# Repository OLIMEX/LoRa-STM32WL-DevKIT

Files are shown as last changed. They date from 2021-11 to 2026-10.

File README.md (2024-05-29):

# LoRa-STM32WL-DevKIT
STM32WL SOC LoRa / LoRaWAN development board with JTAG debugger and sensors for light (photoresistor), temperature and humidity (AHT20, BME280 in older revisions), and 3-axis digital magnetometer (IIS2MDCTR)

Product page: https://www.olimex.com/Products/IoT/LoRa/LoRa-STM32WL-DevKit/

## License
* Hardware design is released under CERN OHL v1.2 license
* Software is released under GPL3 License
* Documentation is released under CC BY-SA 3.0

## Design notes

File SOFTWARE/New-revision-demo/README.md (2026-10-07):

# LoRa-STM32WL-DevKIT LoRaWAN demos for BB-STM32WL revision D1

This folder contains two LoRaWAN end-device demo projects for the Olimex
**LoRa-STM32WL-DevKIT**. They are intended **only for boards fitted with a
BB-STM32WL module marked hardware revision D1**.

For BB-STM32WL revision C or older, use the legacy project and instructions in
[`../Old-revision-demo`](../Old-revision-demo/) instead.

> [!IMPORTANT]
> These projects contain the RF front-end control required by BB-STM32WL
> revision D1. Do not use the binaries on an older BB-STM32WL revision. Check
> the revision marking printed on the module before building or programming.

Always connect an antenna suitable for the selected frequency band before
powering the radio or running the demo.

## Included projects

| Project | LoRaWAN region | Intended use | Demo uplink |
| --- | --- | --- | --- |
| [`LoRaWAN/868/LoRaWAN-868MHz`](LoRaWAN/868/LoRaWAN-868MHz/) | EU868 | Europe and other locations where the EU868 regional parameters are permitted | Unconfirmed message on FPort 2 every 10 seconds; 3-byte temperature/battery test payload |
| [`LoRaWAN/915/LoRa-WAN-915MHz`](LoRaWAN/915/LoRa-WAN-915MHz/) | US915 | North America and other locations where the US915 regional parameters are permitted | Confirmed message on FPort 2 every 10 seconds; 3-byte temperature/battery test payload; configured for US915 sub-band 2 |

The demo payload in both projects is encoded as follows:

| Byte(s) | Value |
| --- | --- |
| 0-1 | Signed 16-bit temperature in degrees Celsius, most-significant byte first |
| 2 | Firmware battery scale: `0` is below the configured minimum, `1` is very low, and `254` is full |

Both applications use OTAA, LoRaWAN Class A, the STM32WLE5CCU6 internal
sub-GHz radio, and UART diagnostic output at 115200 baud. The D1 RF switch is
controlled through `FE_CTRL1` on PC13 and `FE_CTRL2` on PB8.

The selected radio band must be legal in the country of operation and must
match both the gateway and the device profile in the LoRaWAN network server.
The customer is responsible for observing local radio regulations, including
duty-cycle and transmit-power limits.

## Software to use

### Editing and building

Use the Eclipse-based [STM32CubeIDE](https://www.st.com/en/development-tools/stm32cubeide.html).
The repository already contains the STM32 HAL, CMSIS, LoRaWAN middleware, and
the Eclipse project metadata, so a separate middleware download is not needed
for a normal build.

The `.ioc` files were generated with:

- STM32CubeMX 6.17.0
- STM32CubeWL firmware package 1.5.0
- GCC / STM32CubeIDE project format

A newer STM32CubeIDE may offer to migrate the project. Back up local changes
before accepting migration. If pin or middleware code must be regenerated,
use STM32CubeMX 6.17.0 with STM32CubeWL 1.5.0 to minimize generated-code
differences.

### Programming the board

Use [OpenOCD](https://openocd.org/) with the board's built-in CMSIS-DAP probe.
The supplied `flash.sh` scripts use USB VID:PID `15ba:0044`, SWD at 1 MHz, and
the OpenOCD `stm32wlx` target.

STM32CubeIDE can build the firmware, but its normal ST-LINK programming flow is
not the programming method for the onboard CMSIS-DAP probe. STM32CubeProgrammer
is also not required for the supplied onboard-probe workflow.

On Linux, the helper script additionally uses `picocom` for the serial log.
On Windows, use OpenOCD to program the ELF file and any serial-terminal program
(for example PuTTY or Tera Term) to view the virtual COM port.

### LoRaWAN service

A compatible LoRaWAN gateway and network server are required. The Things Stack,
ChirpStack, or another standards-compatible LoRaWAN network server can be used.
Create the end device as an OTAA device and select the same regional frequency
plan as the firmware.

## Configure the OTAA credentials

Each physical device must have unique production credentials. Edit
`LoRaWAN/App/se-identity.h` in the selected project and set:

- `LORAWAN_DEVICE_EUI` (DevEUI). If it remains all zero, the firmware derives a
  value from the STM32 unique device information; register the resulting value
  shown in the serial log.
- `LORAWAN_JOIN_EUI` (called AppEUI by LoRaWAN 1.0.x network servers).
- `LORAWAN_GEN_APP_KEY` (AppKey for LoRaWAN 1.0.x).
- `LORAWAN_APP_KEY` (NwkKey for LoRaWAN 1.1.x).

The values included in the source are examples and must not be reused for a
deployed device. Keep production root keys private and do not commit them to a
public repository.

Credential files:

- EU868: `LoRaWAN/868/LoRaWAN-868MHz/LoRaWAN/App/se-identity.h`
- US915: `LoRaWAN/915/LoRa-WAN-915MHz/LoRaWAN/App/se-identity.h`

## Build

### EU868

1. In STM32CubeIDE, select **File > Import > General > Existing Projects into
   Workspace**.
2. Select `LoRaWAN/868/LoRaWAN-868MHz` as the project directory.
3. Select the **Release** configuration and build the `LoRaWAN-868MHz` project.
4. The expected image is
   `LoRaWAN/868/LoRaWAN-868MHz/Release/LoRaWAN-868MHz.elf`.

The outer `LoRaWAN/868` directory also contains an exported source/build copy
and Eclipse metadata. Use the self-contained project path above for a clean
import, and do not import both copies into the same STM32CubeIDE workspace
because they use the same Eclipse project name.

### US915

1. In STM32CubeIDE, select **File > Import > General > Existing Projects into
   Workspace**.
2. Select `LoRaWAN/915/LoRa-WAN-915MHz` as the project directory.
3. Select the **Release** configuration and build the `LoRa-WAN-915MHz` project.
4. The expected image is
   `LoRaWAN/915/LoRa-WAN-915MHz/Release/LoRa-WAN-915MHz.elf`.

## Program and monitor on Linux

Install OpenOCD and picocom, connect the DevKIT's USB port, and run the helper
from the selected project directory:

```sh
# EU868
cd LoRaWAN/868/LoRaWAN-868MHz
./flash.sh

# US915
cd LoRaWAN/915/LoRa-WAN-915MHz
./flash.sh
```

The script erases the target, programs and verifies the Release ELF, resets the
board, and opens `/dev/ttyACM0` at 115200 baud. If the serial port has a
different name, run OpenOCD manually and open the correct port in picocom.

For either project, pass `--erase-nvm` when changing credentials or when a
stored network session prevents a clean join:

```sh
./flash.sh --erase-nvm
```

## Program manually with OpenOCD

Run from the directory that contains the chosen `Release` folder:

```sh
openocd -f interface/cmsis-dap.cfg \
  -c "cmsis_dap_vid_pid 0x15ba 0x0044" \
  -c "transport select swd" \
  -c "adapter speed 1000" \
  -f target/stm32wlx.cfg \
  -c "program Release/PROJECT_NAME.elf verify reset exit"
```

Replace `PROJECT_NAME.elf` with `LoRaWAN-868MHz.elf` or
`LoRa-WAN-915MHz.elf`. The same command structure can be used from Windows
PowerShell or Command Prompt if `openocd` is on `PATH`; omit the Unix line
continuation characters as appropriate.

## Serial output and first join

Open the board's virtual COM port with these settings:

- 115200 baud
- 8 data bits
- no parity
- 1 stop bit
- no flow control

After reset, the firmware prints its LoRaWAN identity and join status. Confirm
that the DevEUI printed by the board is the DevEUI registered in the network
server. A successful OTAA exchange is followed by `JOINED`/`[DONE]` and then
periodic uplink messages.

If the device does not join:

1. Verify that the module is BB-STM32WL revision D1.
2. Verify the antenna and the selected EU868 or US915 project.
3. Check that DevEUI, JoinEUI/AppEUI, AppKey, and NwkKey match the network
   server exactly, including byte order.
4. For US915, configure the gateway/network frequency plan for sub-band 2.
5. Erase the saved LoRaWAN context after changing credentials, then reset and
   try again.
6. Check the 115200-baud serial log for `JOINFAIL`, radio, or programming
   errors.

## Main configuration files

| Setting | File in each project |
| --- | --- |
| OTAA identifiers and keys | `LoRaWAN/App/se-identity.h` |
| Active region, uplink interval, and FPort | `LoRaWAN/App/lora_app.h` |
| Join, transmit, receive, and demo-payload logic | `LoRaWAN/App/lora_app.c` |
| Compiled regional support | `LoRaWAN/Target/lorawan_conf.h` |
| D1 RF front-end switching | `LoRaWAN/Target/radio_board_if.c` and `.h` |
| Clock, GPIO, USART, and MCU configuration | project `.ioc` file |

## References

- [LoRa-STM32WL-DevKIT product page](https://www.olimex.com/Products/IoT/LoRa/LoRa-STM32WL-DevKit/open-source-hardware)
- [Olimex LoRa-STM32WL-DevKIT repository](https://github.com/OLIMEX/LoRa-STM32WL-DevKIT)
- [STM32CubeIDE](https://www.st.com/en/development-tools/stm32cubeide.html)
- [OpenOCD](https://openocd.org/)

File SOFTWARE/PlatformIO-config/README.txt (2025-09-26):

Board description for platformIO. 

It was tested only with the Arduino framework (not cmsis nor stm32cube).

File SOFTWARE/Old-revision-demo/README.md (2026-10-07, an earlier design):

# LoRa-STM32WL-DevKIT demo for BB-STM32WL revision C and older

This folder contains the legacy EU868 LoRaWAN sensor demo for the Olimex
**LoRa-STM32WL-DevKIT** when it is fitted with a **BB-STM32WL hardware revision
C or older** module.

> [!IMPORTANT]
> Do not program this firmware into a BB-STM32WL revision D1 module. Revision
> D1 uses the newer projects and RF front-end handling in
> [`../New-revision-demo`](../New-revision-demo/). Check the revision marking
> printed on the module before programming.

Always connect a suitable 868 MHz antenna before powering the radio or running
the demo.

## What is included

| Path | Purpose |
| --- | --- |
| [`BB-STM32WLE-WAN`](BB-STM32WLE-WAN/) | STM32CubeIDE end-device project for the STM32WLE5CCU6 |
| [`cmsis-dap`](cmsis-dap/) | Source and build files for the STM32L052-based onboard CMSIS-DAP probe; not required for normal end-device development |
| `flashit` | Example OpenOCD command for programming through the onboard CMSIS-DAP probe |

The end-device project is configured for:

- EU868
- LoRaWAN Class A
- OTAA activation
- adaptive data rate enabled
- unconfirmed uplinks
- AHT20 temperature/humidity sensor by default
- IIS2MDC three-axis magnetometer
- ambient-light and supply-voltage ADC readings
- USART1 diagnostic output at 115200 baud

The sensor uplink is attempted approximately every 10 seconds. It contains a
14-byte example payload assembled in `Core/Src/main.c` from supply-voltage,
temperature, humidity, light, pressure, and three magnetometer values. Treat
this as demonstration encoding: review the units and scaling in `main.c` and
define a decoder that matches your application before deployment.

The selected EU868 band must be legal in the country of operation and must
match the gateway and the device profile in the LoRaWAN network server. The
customer is responsible for local duty-cycle and transmit-power requirements.

## Software to use

### Editing and building

For the most reproducible build, use the Eclipse-based
[STM32CubeIDE](https://www.st.com/en/development-tools/stm32cubeide.html) 1.14.0.
The project already includes the `-fcommon` compiler option required by newer
GCC-based STM32CubeIDE versions. A newer IDE can normally import it, but may
offer to migrate the project; back up local changes before accepting migration.

The project configuration was generated with:

- STM32CubeIDE 1.14.0
- STM32CubeMX 6.3.0
- STM32CubeWL firmware package 1.1.0
- GCC toolchain / STM32CubeIDE project format

The repository contains its HAL, CMSIS, LoRaWAN middleware, and sensor drivers,
so no separate firmware package is required for an ordinary build. Use the
listed CubeMX and CubeWL versions if the `.ioc` file must be regenerated, since
regeneration with a newer package can substantially change the legacy source.

### Programming and serial monitor

Use [OpenOCD](https://openocd.org/) with the DevKIT's built-in CMSIS-DAP probe.
The probe uses USB VID:PID `15ba:0044`. STM32CubeIDE is used to build the ELF,
but its normal ST-LINK programming flow is not the programming method for this
onboard probe.

Use picocom, PuTTY, Tera Term, or another serial-terminal program for the log:

- 115200 baud
- 8 data bits
- no parity
- 1 stop bit
- no flow control

### LoRaWAN service

A compatible EU868 LoRaWAN gateway and network server are required. The Things
Stack, ChirpStack, or another standards-compatible LoRaWAN network server can
be used. Register the device for OTAA and select an EU868 frequency plan.

## Configure the hardware sensor variant

The project defaults to AHT20. In
`BB-STM32WLE-WAN/Core/Src/main.c`, the following line is commented:

```c
//#define BMP280
```

- Leave it commented for a board populated with AHT20.
- Uncomment it for a board populated with BMP280/BME280, then rebuild.

Check the sensor fitted to the DevKIT rather than assuming it only from the
BB-STM32WL module revision.

## Configure OTAA credentials

Edit:

`BB-STM32WLE-WAN/LoRaWAN/App/se-identity.h`

Set unique values supplied by the LoRaWAN network-server registration:

- `LORAWAN_DEVICE_EUI` (DevEUI)
- `LORAWAN_JOIN_EUI` (AppEUI in LoRaWAN 1.0.x terminology)
- `LORAWAN_APP_KEY` (application root key)
- `LORAWAN_NWK_KEY` (network root key for LoRaWAN 1.1.x)

`STATIC_DEVICE_EUI` is set to `1`, so the all-zero DevEUI in the supplied source
is used literally; this legacy project does not automatically replace it with
an MCU-derived value. Replace all placeholder identifiers and keys before
attempting to join. Keep production root keys private and do not commit them to
a public repository.

## Select a valid application port

The current source leaves this assignment commented in `Core/Src/main.c`:

```c
//AppData.Port = SENSORS_PAYLOAD_APP_PORT;
```

Before using the sensor uplink, define an application port in the range 1-223
and assign it to `AppData.Port`, for example:

```c
AppData.Port = 2;
```

FPort 0 is reserved for LoRaWAN MAC commands and must not carry the 14-byte
application payload.

## Build

1. Start STM32CubeIDE.
2. Select **File > Import > General > Existing Projects into Workspace**.
3. Select `Old-revision-demo/BB-STM32WLE-WAN` as the project directory.
4. Select the **Release** build configuration.
5. Clean and build the `BB-STM32WLE-WAN` project.

The expected output is:

`BB-STM32WLE-WAN/Release/BB-STM32WLE-WAN.elf`

No prebuilt end-device ELF is included in this folder, so build the project
before programming it.

## Program with OpenOCD

From `Old-revision-demo/BB-STM32WLE-WAN`, run:

```sh
openocd -f interface/cmsis-dap.cfg \
  -c "cmsis_dap_vid_pid 0x15ba 0x0044" \
  -c "transport select swd" \
  -c "adapter speed 4000" \
  -f target/stm32wlx.cfg \
  -c "program Release/BB-STM32WLE-WAN.elf verify reset exit"
```

The `flashit` file contains the original abbreviated example. The command above
adds the Release path, verification, reset, and clean OpenOCD exit.

OpenOCD works on Linux, Windows, and macOS. On Windows, place `openocd` on
`PATH` and enter the command on one line or adapt the line continuations for
PowerShell.

## First run

1. Connect the antenna and the DevKIT USB cable.
2. Open the virtual COM port at 115200 8-N-1.
3. Reset the board.
4. Confirm that the AHT20 or BMP280/BME280 sensor and IIS2MDC magnetometer are
   detected in the serial output.
5. Check the OTAA result for `JOINED` or `JOIN FAILED`.
6. After a successful join, monitor `SEND REQUEST` and the uplink counter.

If the device does not join, verify the hardware revision, antenna, EU868
frequency plan, DevEUI, JoinEUI/AppEUI, AppKey, and NwkKey. Pay attention to
byte order when copying identifiers and keys from the network server.

## Onboard CMSIS-DAP firmware

The `cmsis-dap` directory is the firmware project for the DevKIT's separate
STM32L052 debugger/interface microcontroller. It is not LoRaWAN application
code and does not need to be built or programmed for normal use. Reprogramming
the interface MCU incorrectly can disable onboard programming and the virtual
COM port; only use that directory when intentionally restoring or developing
the debugger firmware.

## Main configuration files

| Setting | File |
| --- | --- |
| Hardware pin, clock, peripheral, and middleware setup | `BB-STM32WLE-WAN/BB-STM32WLE-WAN.ioc` |
| Sensor selection, sampling, payload, and send interval | `BB-STM32WLE-WAN/Core/Src/main.c` |
| OTAA identifiers and keys | `BB-STM32WLE-WAN/LoRaWAN/App/se-identity.h` |
| Region, class, activation, ADR, and confirmed/unconfirmed mode | `BB-STM32WLE-WAN/LoRaWAN/App/lora_app.h` |
| Join, receive, and transmit callbacks | `BB-STM32WLE-WAN/LoRaWAN/App/lora_app.c` |
| Legacy radio-board support | `BB-STM32WLE-WAN/LoRaWAN/Target/` |

## References

- [LoRa-STM32WL-DevKIT product page](https://www.olimex.com/Products/IoT/LoRa/LoRa-STM32WL-DevKit/open-source-hardware)
- [Olimex LoRa-STM32WL-DevKIT repository](https://github.com/OLIMEX/LoRa-STM32WL-DevKIT)
- [STM32CubeIDE](https://www.st.com/en/development-tools/stm32cubeide.html)
- [OpenOCD](https://openocd.org/)

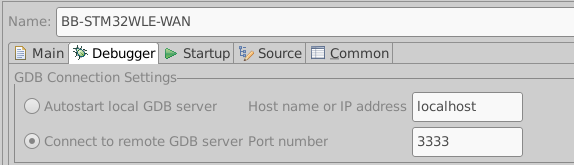
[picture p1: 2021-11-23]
DOCUMENTS/stm32cubeide_use_openocd.png

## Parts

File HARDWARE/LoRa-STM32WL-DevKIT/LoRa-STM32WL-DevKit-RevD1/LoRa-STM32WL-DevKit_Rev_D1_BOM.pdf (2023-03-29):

LoRa-STM32WL-DevKit_RevD1_BOM | 11/11/2022
Qty | Designation | Package | Designator
2 22R | | R_0402_5MIL_DWS | R7,R12
3 220R | | R_0402_5MIL_DWS | R1,R5,R6
2 1.5K | | R_0402_5MIL_DWS | R2,R4
3 2.2K | | R_0402_5MIL_DWS | R3,R14,R16
7 10K | | R_0402_5MIL_DWS | R9,R10,R11,R13,R15, R17,R18
1 100K | | R_0402_5MIL_DWS | R19
3 100nF/10V/20%/X5R | | C_0402_5MIL_DWS | C2,C3,C12
3 220nF/+80-20%/10VDC | | C_0402_5MIL_DWS | C6,C8,C10
2 2.2uF/6.3V/20% | | C_0402_5MIL_DWS | C5,C11
3 4.7uF/6.3V | | C_0603_5MIL_DWS | C1,C4,C7
1 FB0805/600R/2A | | L_0805_5MIL_DWS | L1
1 1N5819(S4 SOD-123) | | SOD-123_KA | D1
1 LED/0603/YELLOW/150 mCd | | LED_0603_KA | LED3
1 LED/0603/RED/300 mCd | | LED_0603_KA | LED1
1 LED/0603/GREEN/300 mCd | | LED_0603_KA | LED2
2 WPM2015-3/TR | | SOT23 | FET1,FET2
1 SNS-LDR5MM | | R_PHOTO-Device | R8
1 AHT20 | | AHT20 | U5
1 ME6210A33PG | | SOT89 | U1
1 IIS2MDCTR | | LGA-12_2X2_0.5 | U3
1 STM32L052K8U3 | | QFN32_EP(33)_5.00x5.00x 0.90mm_Pitch_0.50mm | U2
1 P-B-V-10-LF | | GBH-254-SMT-10 | UEXT1
1 BTH-DP-AA-LF(BH311P) | | BATTERY-1xAA | BAT1
1 MISB-SWMM-5B-LF | | USB-MICRO_MISB-SWMM-5B_LF | USB1
2 PN_F-D-1X12-LF | | BB-STM32WL | BB-STM32WL_PLATFORM1
1 HN1X10 | | HN1x10 | CON1
1 HN1x2 | | HN1x2_Jumper | BATTERY
2 T1107A(6x3,8x2,5MM) | | T1107A(6x3,8x2,5MM) | BUTTON,RESET1
1 SJ_Closed_Board_Mounted | | SJ_1_SMALLER_TIED | SJ1
1 NA(BME280) | | BME280 | U4
1 NA | | WU02S | SB1
1 NA(4.7uF/6.3V) | C_0603_5MIL_DWS | C9
1 22uF/6.3V/0603 | Добавя се ръчно на FET2(1-2 pin) | C13

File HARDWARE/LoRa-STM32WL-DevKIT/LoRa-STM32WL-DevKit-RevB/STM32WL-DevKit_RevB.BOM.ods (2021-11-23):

Designation | Quantity | Designator | Package
SMD RES 0402 1.5 K 5% | 2 | R2,R4 | R_0402_5MIL_DWS
SMD CAP 0402 100 NF 10% 10VDC | 3 | C2,C3,C12 | C_0402_5MIL_DWS
SMD RES 0402 10 K 5% | 7 | R9,R10,R11,R13,R15,R17,R18 | R_0402_5MIL_DWS
SMD DIODE 1N5819 (S4 SOD-123) | 1 | D1 | SOD-123_KA
SMD RES 0402 2.2 K 5% | 3 | R3,R14,R16 | R_0402_5MIL_DWS
SMD CAP 0402 2.2 UF 6.3V 20% | 2 | C5, C11 | C_0402_5MIL_DWS
SMD RES 0402 220 OHM 5% | 3 | R1,R5,R6 | R_0402_5MIL_DWS
SMD CAP 0402 220 NF +80-20% 10VDC | 3 | C6,C8,C10 | C_0402_5MIL_DWS
SMD RES 0402 22 OHM 5% | 2 | R7,R12 | R_0402_5MIL_DWS
SMD CAP 0603 4.7 UF 6.3V | 4 | C1,C4,C7,C9 | C_0603_5MIL_DWS
CON PN 1 X 16 (F-D-1X16-LF) | 2 | MOD1 | BB-STM32WLE
SMD CON P-B-V-10-LF | 1 | UEXT1 | GBH-254-SMT-10
SMD IC BME280 | 1 | U4 | BME280
СЪЕДИНИТЕЛ BTH-DP-AA-LF (BH311P) | 1 | BAT1 | BATTERY-1xAA
РЕЙКА 1 X 40 (HN 1X40) | ¼+1/20 | CON1, JP2 | HN1x10
SMD LED 0603 GREEN 300 mCd | 1 | LED2 | LED_0603_KA
SMD IC IIS2MDCTR | 1 | U3 | LGA-12_2X2_0.5
SMD IC ME6210A33PG | 1 | U1 | SOT89
SMD LED 0603 RED 300 mCd | 1 | LED1 | LED_0603_KA
SNS-LDR5MM | 1 | R8 | R_PHOTO
STM32L052K8Ux | 1 | U2 | QFN-32_EP_5.3x5.3_Pitch0.5mm
SMD SWITCH БУТОН T1107А 6x3.8x2.5mm | 2 | SW1,SW2 | T1107A(6x3,8x2,5MM)
SMD CON MISB-SWMM-5B-LF | 1 | USB1 | USB-MICRO_MISB-SWMM-5B_LF
SMD TR WPM2015-3/TR | 1 | FET1 | SOT23
SMD LED 0603 YELLOW 150 mCd | 1 | LED3 | LED_0603_KA

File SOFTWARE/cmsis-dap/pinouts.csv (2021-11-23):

Position | Name | Type | Signal | Label | AF0 | AF1 | AF2 | AF3 | AF4 | AF5 | AF6 | AF7
1 | VDD | Power
2 | PC14-OSC32_IN | I/O
3 | PC15-OSC32_OUT | I/O
4 | NRST | Reset
5 | VDDA | Power
6 | PA0 | I/O |  |  |  |  | TIM2_CH1 | TSC_G1_IO1 | USART2_CTS | TIM2_ETR |  | COMP1_OUT
7 | PA1 | I/O |  |  | EVENTOUT |  | TIM2_CH2 | TSC_G1_IO2 | USART2_DE/USART2_RTS | TIM21_ETR
8 | PA2 | I/O |  |  | TIM21_CH1 |  | TIM2_CH3 | TSC_G1_IO3 | USART2_TX |  |  | COMP2_OUT
9 | PA3 | I/O |  |  | TIM21_CH2 |  | TIM2_CH4 | TSC_G1_IO4 | USART2_RX
10 | PA4 | Output | GPIO_Output | TMS | SPI1_NSS |  |  | TSC_G2_IO1 | USART2_CK | TIM22_ETR
11 | PA5 | Input | GPIO_Input | TCK | SPI1_SCK |  | TIM2_ETR | TSC_G2_IO2 |  | TIM2_CH1
12 | PA6 | Input | GPIO_Input | TDO | SPI1_MISO |  |  | TSC_G2_IO3 |  | TIM22_CH1 | EVENTOUT | COMP1_OUT
13 | PA7 | Output | GPIO_Output | TDI | SPI1_MOSI |  |  | TSC_G2_IO4 |  | TIM22_CH2 | EVENTOUT | COMP2_OUT
14 | PB0 | I/O |  |  | EVENTOUT |  |  | TSC_G3_IO2
15 | PB1 | I/O |  |  |  |  |  | TSC_G3_IO3
16 | PB2 | I/O |  |  |  |  | LPTIM1_OUT | TSC_G3_IO4
17 | VDD | Power
18 | PA8 | Output | GPIO_Output | USB_REC | RCC_MCO |  | CRS_SYNC | EVENTOUT | USART1_CK
19 | PA9 | I/O |  |  | RCC_MCO |  |  | TSC_G4_IO1 | USART1_TX
20 | PA10 | I/O |  |  |  |  |  | TSC_G4_IO2 | USART1_RX
21 | PA11 | I/O | USB_DM |  | SPI1_MISO |  | EVENTOUT | TSC_G4_IO3 | USART1_CTS |  |  | COMP1_OUT
22 | PA12 | I/O | USB_DP |  | SPI1_MOSI |  | EVENTOUT | TSC_G4_IO4 | USART1_DE/USART1_RTS |  |  | COMP2_OUT
23 | PA13 | Output | GPIO_Output | SWDIO | SYS_SWDIO |  | USB_NOE
24 | PA14 | Output | GPIO_Output | SWCLK | SYS_SWCLK |  |  |  | USART2_TX
25 | PA15 | I/O |  |  | SPI1_NSS |  | TIM2_ETR | EVENTOUT | USART2_RX | TIM2_CH1
26 | PB3 | Output | GPIO_Output | RLED | SPI1_SCK |  | TIM2_CH2 | TSC_G5_IO1 | EVENTOUT
27 | PB4 | Output | GPIO_Output | GLED | SPI1_MISO |  | EVENTOUT | TSC_G5_IO2 | TIM22_CH1
28 | PB5 | I/O |  |  | SPI1_MOSI |  | LPTIM1_IN1 | I2C1_SMBA | TIM22_CH2
29 | PB6 | I/O |  |  | USART1_TX | I2C1_SCL | LPTIM1_ETR | TSC_G5_IO3
30 | PB7 | I/O |  |  | USART1_RX | I2C1_SDA | LPTIM1_IN2 | TSC_G5_IO4
31 | BOOT0 | Boot
32 | PB8 | Output | GPIO_Output | NRESET |  |  |  | TSC_SYNC | I2C1_SCL

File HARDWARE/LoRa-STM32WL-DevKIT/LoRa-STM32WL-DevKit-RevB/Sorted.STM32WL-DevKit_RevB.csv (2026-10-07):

Designation | Quantity | Designator | Package
1.5K | 2 | R2,R4 | R_0402_5MIL_DWS
100n | 3 | C2,C3,C12 | C_0402_5MIL_DWS
10K | 2 | R9,R18 | R_0402_SMALL
10K | 3 | R13,R15,R17 | R_0402_5MIL_DWS
10k | 2 | R10,R11 | R_0402_5MIL_DWS
1N5819 | 1 | D1 | SOD-123_KA
2.2 uF | 1 | C11 | C_0402_5MIL_DWS
2.2K | 3 | R3,R14,R16 | R_0402_5MIL_DWS
2.2uF_6.3V | 1 | C5 | C_0402_5MIL_DWS
220R | 3 | R1,R5,R6 | R_0402_5MIL_DWS
220nF | 3 | C6,C8,C10 | C_0402_5MIL_DWS
22R | 2 | R7,R12 | R_0402_5MIL_DWS
4.7uF_6.3V | 4 | C1,C4,C7,C9 | C_0603_5MIL_DWS
BB-STM32WL | 1 | MOD1 | BB-STM32WLE
BH10S | 1 | UEXT1 | GBH-254-SMT-10
BME280 | 1 | U4 | BME280
Battery | 1 | BAT1 | BATTERY-1xAA
CON10 | 1 | CON1 | HN1x10
GLED | 1 | LED2 | LED_0603_KA
IIS2MDC | 1 | U3 | LGA-12_2X2_0.5
JP1E | 1 | JP2 | HN1x2_Jumper
ME6210-SOT89 | 1 | U1 | SOT89
RLED | 1 | LED1 | LED_0603_KA
R_PHOTO-Device | 1 | R8 | R_PHOTO
SJ | 1 | SB1 | WU02S
SJ_Closed | 1 | SJ1 | SJ_1_SMALLER_TIED
STM32L052K8Ux | 1 | U2 | QFN-32_EP_5.3x5.3_Pitch0.5mm
T1107A(6x3,8x2,5MM) | 2 | SW1,SW2 | T1107A(6x3,8x2,5MM)
USB-DEBUG | 1 | USB1 | USB-MICRO_MISB-SWMM-5B_LF
WPM2015 | 1 | FET1 | SOT23
YLED | 1 | LED3 | LED_0603_KA

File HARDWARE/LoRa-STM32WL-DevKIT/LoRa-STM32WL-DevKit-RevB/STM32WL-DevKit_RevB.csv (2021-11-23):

Id | Designator | Package | Quantity | Designation | Supplier and ref
1 | SB1 | WU02S | 1 | SJ
2 | U2 | QFN-32_EP_5.3x5.3_Pitch0.5mm | 1 | STM32L052K8Ux
3 | C5 | C_0402_5MIL_DWS | 1 | 2.2uF_6.3V
4 | U1 | SOT89 | 1 | ME6210-SOT89
5 | USB1 | USB-MICRO_MISB-SWMM-5B_LF | 1 | USB-DEBUG
6 | D1 | SOD-123_KA | 1 | 1N5819
7 | FET1 | SOT23 | 1 | WPM2015
8 | JP2 | HN1x2_Jumper | 1 | JP1E
9 | LED1 | LED_0603_KA | 1 | RLED
10 | LED2 | LED_0603_KA | 1 | GLED
11 | LED3 | LED_0603_KA | 1 | YLED
12 | R1,R6,R5 | R_0402_5MIL_DWS | 3 | 220R
13 | R2,R4 | R_0402_5MIL_DWS | 2 | 1.5K
14 | R3,R14,R16 | R_0402_5MIL_DWS | 3 | 2.2K
15 | R7,R12 | R_0402_5MIL_DWS | 2 | 22R
16 | R13,R15,R17 | R_0402_5MIL_DWS | 3 | 10K
17 | R18,R9 | R_0402_SMALL | 2 | 10K
18 | C11 | C_0402_5MIL_DWS | 1 | 2.2 uF
19 | C3,C12,C2 | C_0402_5MIL_DWS | 3 | 100n
20 | C4,C1,C9,C7 | C_0603_5MIL_DWS | 4 | 4.7uF_6.3V
21 | MOD1 | BB-STM32WLE | 1 | BB-STM32WL
22 | , | OLIMEX_LOGO_TB | 2
23 |  | LOGO_RECYCLEBIN_1 | 1
24 |  | LOGO_OPENHARDWARE_8x8 | 1
25 | REF** | CE_Sign | 1 | CE_Sign
26 | SJ1 | SJ_1_SMALLER_TIED | 1 | SJ_Closed
27 | Ref*,Ref* | Fiducial1x3_transp | 2 | Val**
28 | MountingHole*,MountingHole*,MountingHole*,MountingHole* | Rubber_feet | 4 | Rubber_feet
29 | U3 | LGA-12_2X2_0.5 | 1 | IIS2MDC
30 | U4 | BME280 | 1 | BME280
31 | UEXT1 | GBH-254-SMT-10 | 1 | BH10S
32 | SW2,SW1 | T1107A(6x3,8x2,5MM) | 2 | T1107A(6x3,8x2,5MM)
33 | R11,R10 | R_0402_5MIL_DWS | 2 | 10k
34 | R8 | R_PHOTO | 1 | R_PHOTO-Device
35 | CON1 | HN1x10 | 1 | CON10
36 | C10,C8,C6 | C_0402_5MIL_DWS | 3 | 220nF
37 | BAT1 | BATTERY-1xAA | 1 | Battery

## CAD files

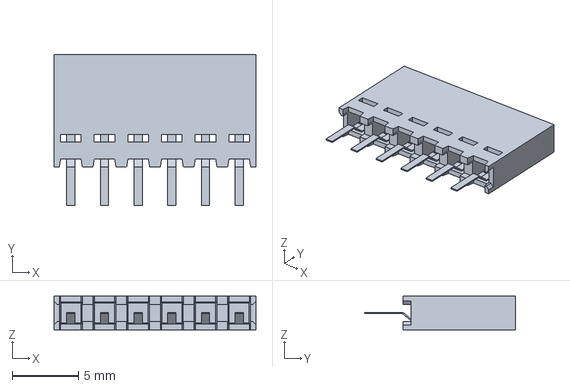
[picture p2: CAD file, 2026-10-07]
HARDWARE/LoRa-STM32WL-DevKIT/LoRa-STM32WL-DevKit-RevB/3d/PN1x6-Molex_C-Grid_901471106_1x06_P2.54mm_Vertical.step
15.2 x 11.4 x 2.54 mm

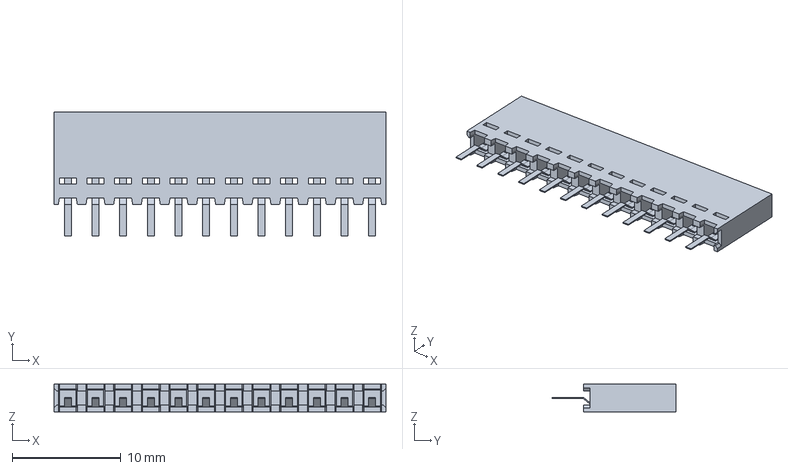
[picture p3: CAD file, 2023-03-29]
HARDWARE/LoRa-STM32WL-DevKIT/LoRa-STM32WL-DevKit-RevD1/3d/PN1x12-Molex_C-Grid_901471112_1x12_P2.54mm_Vertical.step
30.5 x 11.4 x 2.54 mm

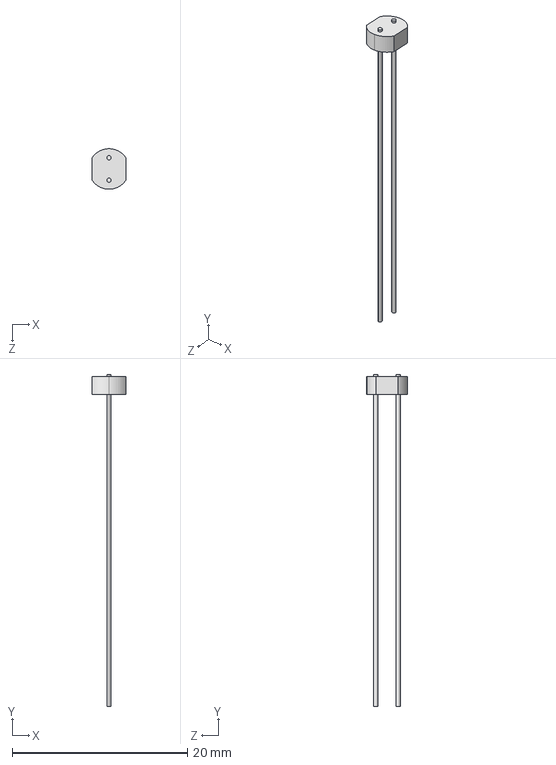
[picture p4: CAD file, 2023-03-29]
HARDWARE/LoRa-STM32WL-DevKIT/LoRa-STM32WL-DevKit-RevD1/3d/User_Library-Photoresistor.step
3.91 x 37.8 x 4.62 mm

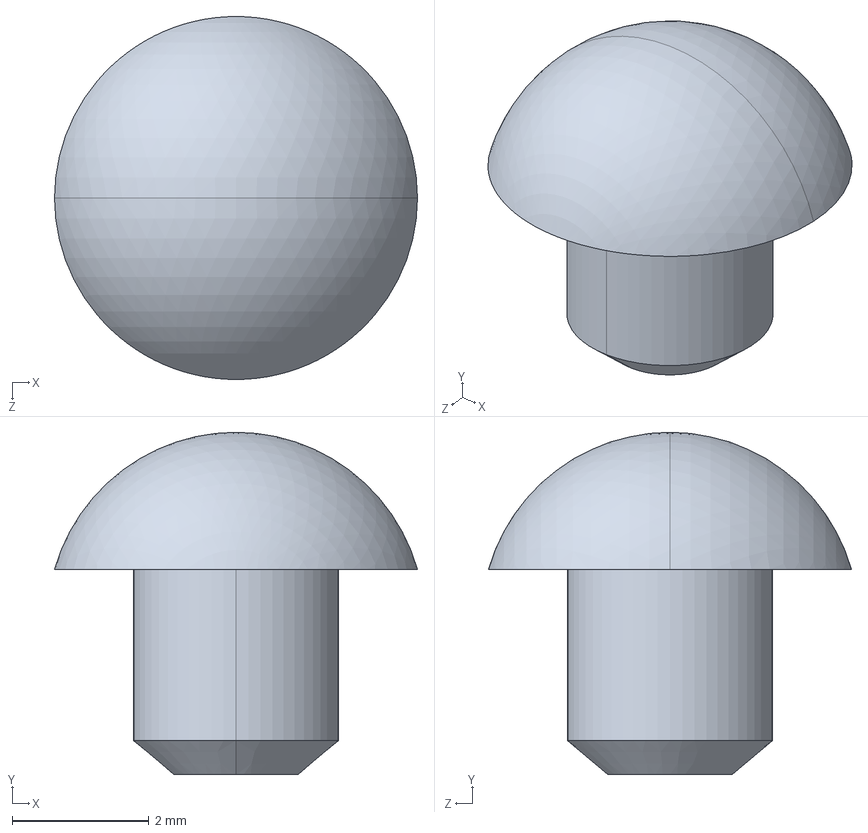
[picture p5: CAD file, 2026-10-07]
HARDWARE/LoRa-STM32WL-DevKIT/LoRa-STM32WL-DevKit-RevB/3d/rubber_feet.step
5.30 x 5.00 x 5.30 mm

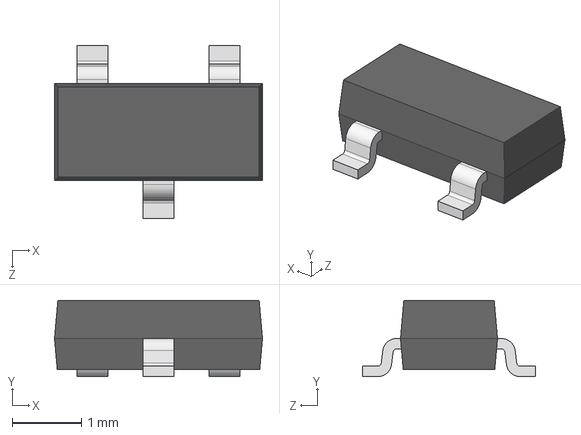
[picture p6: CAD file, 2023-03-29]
HARDWARE/LoRa-STM32WL-DevKIT/LoRa-STM32WL-DevKit-RevD1/3d/SOT-23.step
3.00 x 1.10 x 2.50 mm

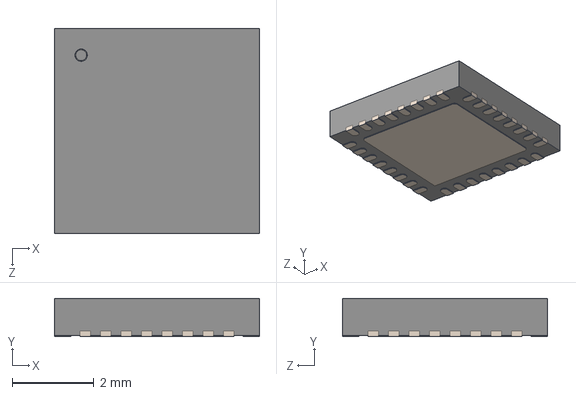
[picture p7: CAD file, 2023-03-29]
HARDWARE/LoRa-STM32WL-DevKIT/LoRa-STM32WL-DevKit-RevB/3d/QFN32_5x5.step
5.00 x 0.93 x 5.00 mm

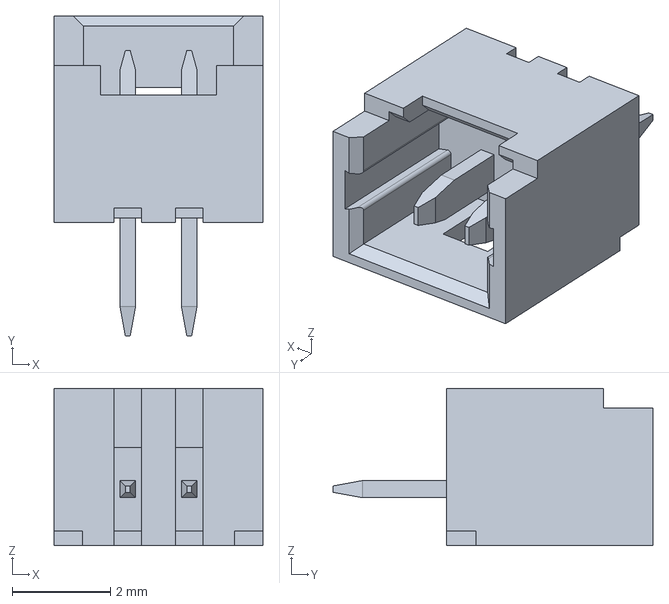
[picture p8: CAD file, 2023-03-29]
HARDWARE/LoRa-STM32WL-DevKIT/LoRa-STM32WL-DevKit-RevD1/3d/WU02S-Molex_PicoBlade_530470210_1x02_P1.25mm_Vertical.step
4.25 x 6.50 x 3.20 mm

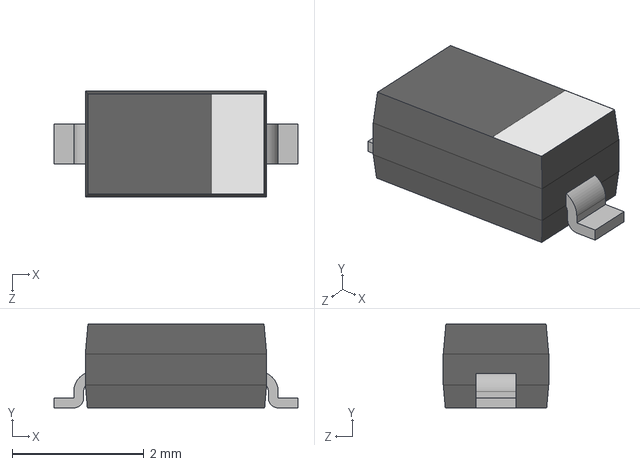
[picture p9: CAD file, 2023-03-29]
HARDWARE/LoRa-STM32WL-DevKIT/LoRa-STM32WL-DevKit-RevB/3d/SOD123.step
3.70 x 1.27 x 1.60 mm

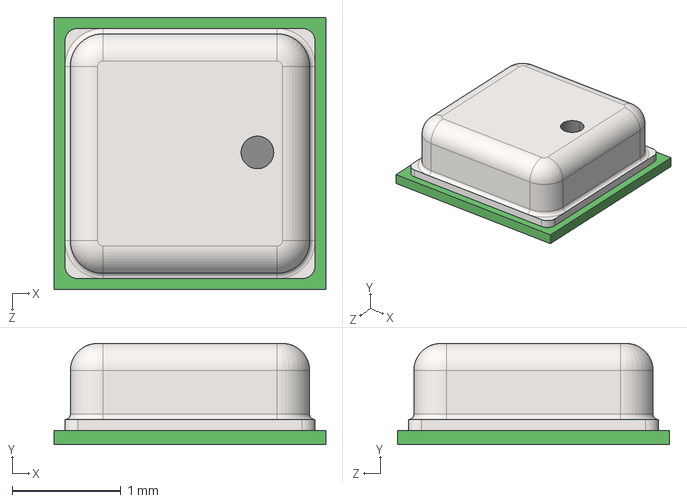
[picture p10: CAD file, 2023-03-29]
HARDWARE/LoRa-STM32WL-DevKIT/LoRa-STM32WL-DevKit-RevD1/3d/BME280-1.STEP
2.50 x 0.93 x 2.50 mm

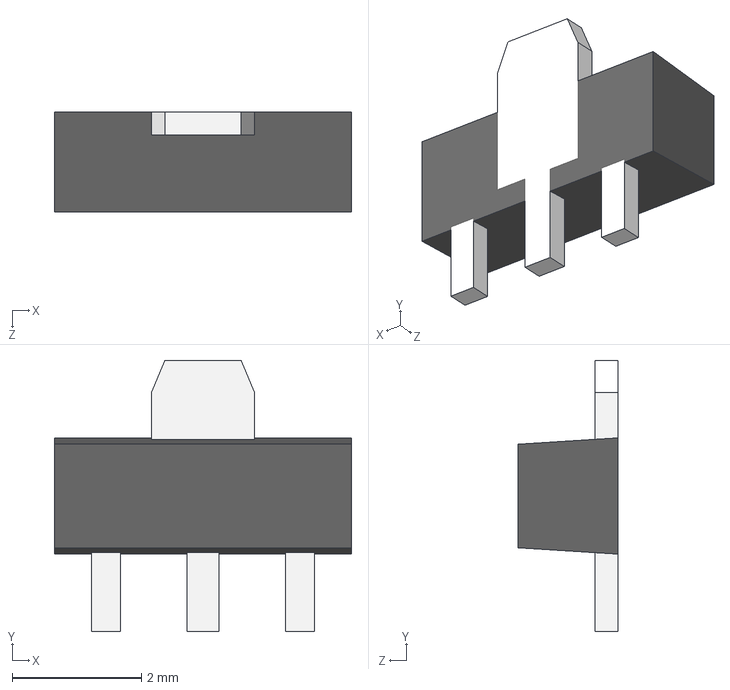
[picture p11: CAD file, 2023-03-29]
HARDWARE/LoRa-STM32WL-DevKIT/LoRa-STM32WL-DevKit-RevB/3d/SOT89-1.STEP
4.60 x 4.20 x 1.55 mm

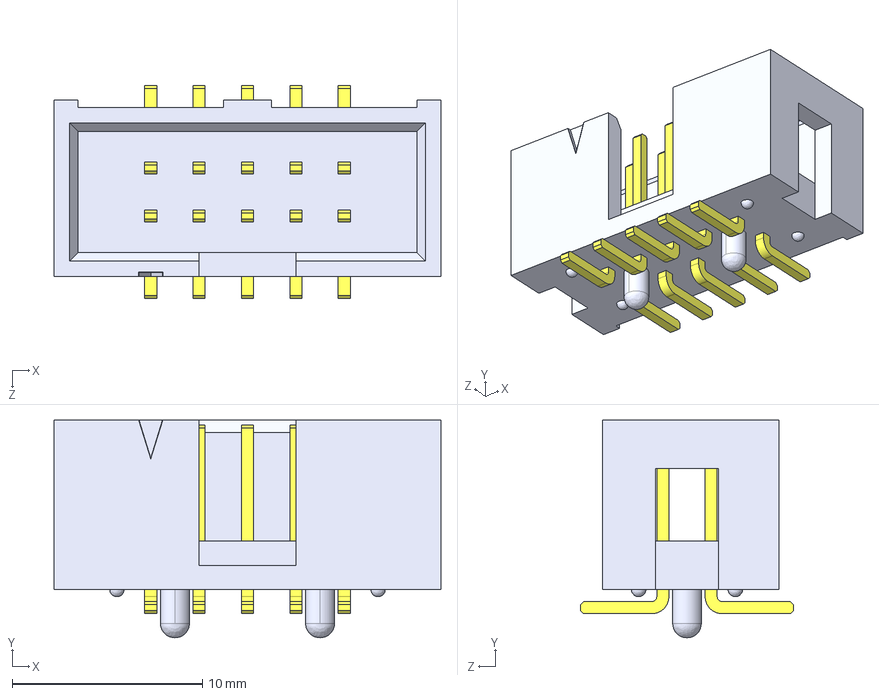
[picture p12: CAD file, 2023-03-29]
HARDWARE/LoRa-STM32WL-DevKIT/LoRa-STM32WL-DevKit-RevB/3d/UEXT-SMD.STEP
20.3 x 11.4 x 11.2 mm
User Library-HTST-105-01-F-DV-A__HTST-105-01-DV-A_header
User Library-HTST-105-01-F-DV-A__HTST-First_Position_Indicator
User Library-HTST-105-01-F-DV-A__T-1S6-05-01-DV_

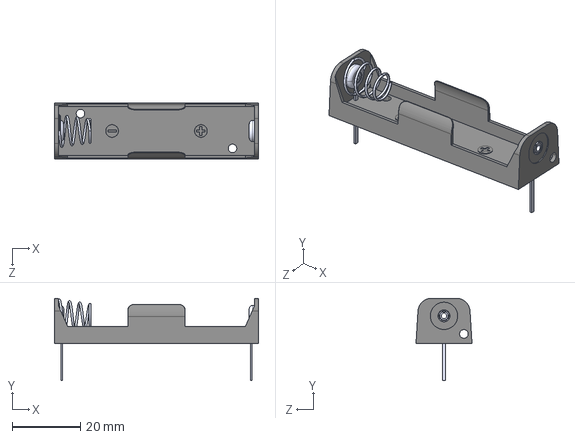
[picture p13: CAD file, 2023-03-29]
HARDWARE/LoRa-STM32WL-DevKIT/LoRa-STM32WL-DevKit-RevB/3d/BCAAPC.STEP
59.7 x 24.1 x 16.4 mm

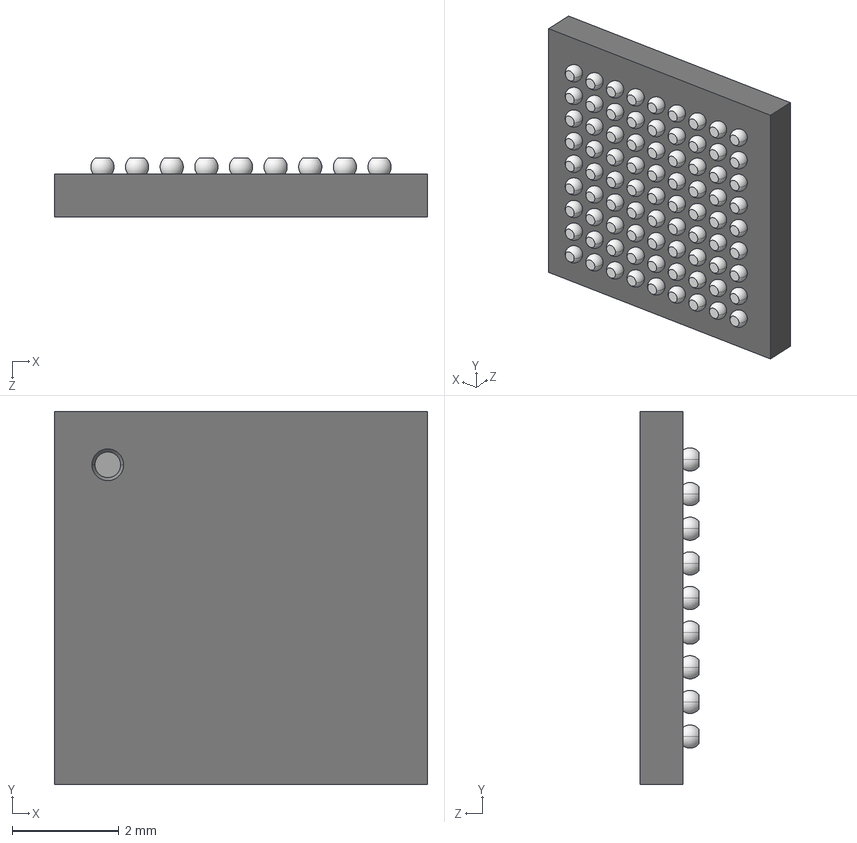
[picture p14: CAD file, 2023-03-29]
HARDWARE/LoRa-STM32WL-DevKIT/LoRa-STM32WL-DevKit-RevB/3d/bga-81-2.step
7.00 x 7.00 x 1.10 mm

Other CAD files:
HARDWARE/LoRa-STM32WL-DevKIT/LoRa-STM32WL-DevKit-RevD1/3d/Bosch_BME280.step
HARDWARE/LoRa-STM32WL-DevKIT/LoRa-STM32WL-DevKit-RevB/3d/18650.step
HARDWARE/LoRa-STM32WL-DevKIT/LoRa-STM32WL-DevKit-RevB/3d/434121043836 (rev1).stp
HARDWARE/LoRa-STM32WL-DevKIT/LoRa-STM32WL-DevKit-RevB/3d/BAT_1xAA_HOLDER.step
HARDWARE/LoRa-STM32WL-DevKIT/LoRa-STM32WL-DevKit-RevB/3d/Bosch_BME280.step
HARDWARE/LoRa-STM32WL-DevKIT/LoRa-STM32WL-DevKit-RevB/3d/HN1x10-PinHeader_1x10_P2.54mm_Vertical.step
HARDWARE/LoRa-STM32WL-DevKIT/LoRa-STM32WL-DevKit-RevB/3d/HN1x2-PinHeader_1x02_P2.54mm_Vertical.step
HARDWARE/LoRa-STM32WL-DevKIT/LoRa-STM32WL-DevKit-RevB/3d/usb_micro_4p.stp
HARDWARE/LoRa-STM32WL-DevKIT/LoRa-STM32WL-DevKit-RevD1/3d/434121043836 (rev1).stp
HARDWARE/LoRa-STM32WL-DevKIT/LoRa-STM32WL-DevKit-RevD1/3d/BAT_1xAA_HOLDER.step
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

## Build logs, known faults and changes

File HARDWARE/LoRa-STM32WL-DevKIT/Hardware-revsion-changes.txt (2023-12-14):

LoRa-STM32WL-DevKit

This hardware design is made with KiCAD. If you have problems opening the design, try getting newer KiCAD version (probably even latest nightly build).

Hardware revision D1

---

Overview: major changes

1. Changed temperature and humidty sensor to AHT20 (from BME280). This requires software changes.

2. FET2 changed to P-MOS and added processor control from PB12 pin. FET2 controlls UEXT and AHT20 power supply. To allow the powering set PB12 to low.

3. Adjusted several component labels and improved the schematic layout.

4. Changes of several capacitors and other less important components.

Hardware revision B

---

Overview: initial board release

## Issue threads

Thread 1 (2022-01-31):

Error building demo project

dmitry-yudakov, 2022-01-31:
I'm trying to build [SOFTWARE/BB-STM32WLE-WAN](https://github.com/OLIMEX/LoRa-STM32WL-DevKIT/tree/main/SOFTWARE/BB-STM32WLE-WAN) project with CubeIDE but it gives me error about missing `iis2mdc/iis2mdc_reg.h`

```
make -j7 all
arm-none-eabi-gcc "../Core/Src/main.c" -mcpu=cortex-m4 -std=gnu11 -g3 -DDEBUG -DCORE_CM4 -DUSE_HAL_DRIVER -DSTM32WLE5xx -c -I../Core/Inc -I../Utilities/trace/adv_trace -I../Drivers/STM32WLxx_HAL_Driver/Inc -I../Drivers/STM32WLxx_HAL_Driver/Inc/Legacy -I../Utilities/misc -I../Utilities/sequencer -I../Utilities/timer -I../Utilities/lpm/tiny_lpm -I../Middlewares/Third_Party/SubGHz_Phy -I../Middlewares/Third_Party/SubGHz_Phy/stm32_radio_driver -I../Drivers/CMSIS/Device/ST/STM32WLxx/Include -I../Drivers/CMSIS/Include -I../LoRaWAN/App -I../LoRaWAN/Target -I../Middlewares/Third_Party/LoRaWAN/LmHandler/Packages -I../Middlewares/Third_Party/LoRaWAN/Crypto -I../Middlewares/Third_Party/LoRaWAN/Mac/Region -I../Middlewares/Third_Party/LoRaWAN/Mac -I../Middlewares/Third_Party/LoRaWAN/LmHandler -I../Middlewares/Third_Party/LoRaWAN/Utilities -O0 -ffunction-sections -fdata-sections -Wall -fstack-usage -MMD -MP -MF"Core/Src/main.d" -MT"Core/Src/main.o"  -mfloat-abi=soft -mthumb -o "Core/Src/main.o"

../Core/Src/main.c:29:10: fatal error: iis2mdc/iis2mdc_reg.h: No such file or directory
   29 | #include "iis2mdc/iis2mdc_reg.h"
      |          ^~~~~~~~~~~~~~~~~~~~~~~
compilation terminated.
```

It seems `iis2mdc` in [SOFTWARE/BB-STM32WLE-WAN/Core/Src](https://github.com/OLIMEX/LoRa-STM32WL-DevKIT/tree/main/SOFTWARE/BB-STM32WLE-WAN/Core/Src) might be a symbolic link or something but in my cloned project it's just an empty directory.

I thought it might be a git submodule but I cannot find `.gitmodules` file anywhere.

Should I somehow import this library?

I tried cloning couple of projects like [this](https://github.com/STMicroelectronics/STM32CubeU5) or [this](https://github.com/stm32duino/IIS2MDC) and use them in place of `iis2mdc` but it results in other errors and feels like a wrong direction.

Thank you in advance.

DanKoloff, 2022-02-01:
Exactly it seems like it is some link instead of real deal. I think the original folder had .git inside and got ignored. Try with these two in the archive:

[iis2mdc.zip](https://github.com/OLIMEX/LoRa-STM32WL-DevKIT/files/7979143/iis2mdc.zip)

dmitry-yudakov, 2022-02-01:
Yep, it builds with these files. Thank you!

I'll prepare a PR.

DanKoloff, 2022-02-02:
Thank you for the report and testing. I will upload the missing files to the repo later. Cheers!

Closed 2022-02-02.

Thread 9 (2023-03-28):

Release revision C/D schematics and KiCad project

KloudJack, 2023-03-28:
There have been design changes between the currently shipped revision C/D dev kits and the revision B schematics/project files available here.

One such example is the addition of the FET2 transistor to control the `VDD` pins on the `UEXT1` connector and `CON1` header.

Please make the revision C/D development kit schematics and KiCad project files available in this repository.

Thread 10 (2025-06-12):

Build failure

fabltd, 2025-06-12:
When trying to build the example code the following error occours

```
/Applications/STM32CubeIDE.app/Contents/Eclipse/plugins/com.st.stm32cube.ide.mcu.externaltools.gnu-tools-for-stm32.13.3.rel1.macos64_1.0.0.202411102158/tools/bin/../lib/gcc/arm-none-eabi/13.3.1/../../../../arm-none-eabi/bin/ld: ./Core/Src/subghz.o: in function `MX_SUBGHZ_Init':
/Users/xx/Downloads/LoRa-STM32WL-DevKIT-main/SOFTWARE/BB-STM32WLE-WAN/Debug/../Core/Src/subghz.c:31: multiple definition of `MX_SUBGHZ_Init'; ./Core/Src/main.o:/Users/xx/Downloads/LoRa-STM32WL-DevKIT-main/SOFTWARE/BB-STM32WLE-WAN/Debug/../Core/Src/main.c:665: first defined here
/Applications/STM32CubeIDE.app/Contents/Eclipse/plugins/com.st.stm32cube.ide.mcu.externaltools.gnu-tools-for-stm32.13.3.rel1.macos64_1.0.0.202411102158/tools/bin/../lib/gcc/arm-none-eabi/13.3.1/../../../../arm-none-eabi/bin/ld: warning: BB-STM32WLE-WAN.elf has a LOAD segment with RWX permissions
collect2: error: ld returned 1 exit status
make: *** [makefile:81: BB-STM32WLE-WAN.elf] Error 1
"make -j9 all" terminated with exit code 2. Build might be incomplete.
```

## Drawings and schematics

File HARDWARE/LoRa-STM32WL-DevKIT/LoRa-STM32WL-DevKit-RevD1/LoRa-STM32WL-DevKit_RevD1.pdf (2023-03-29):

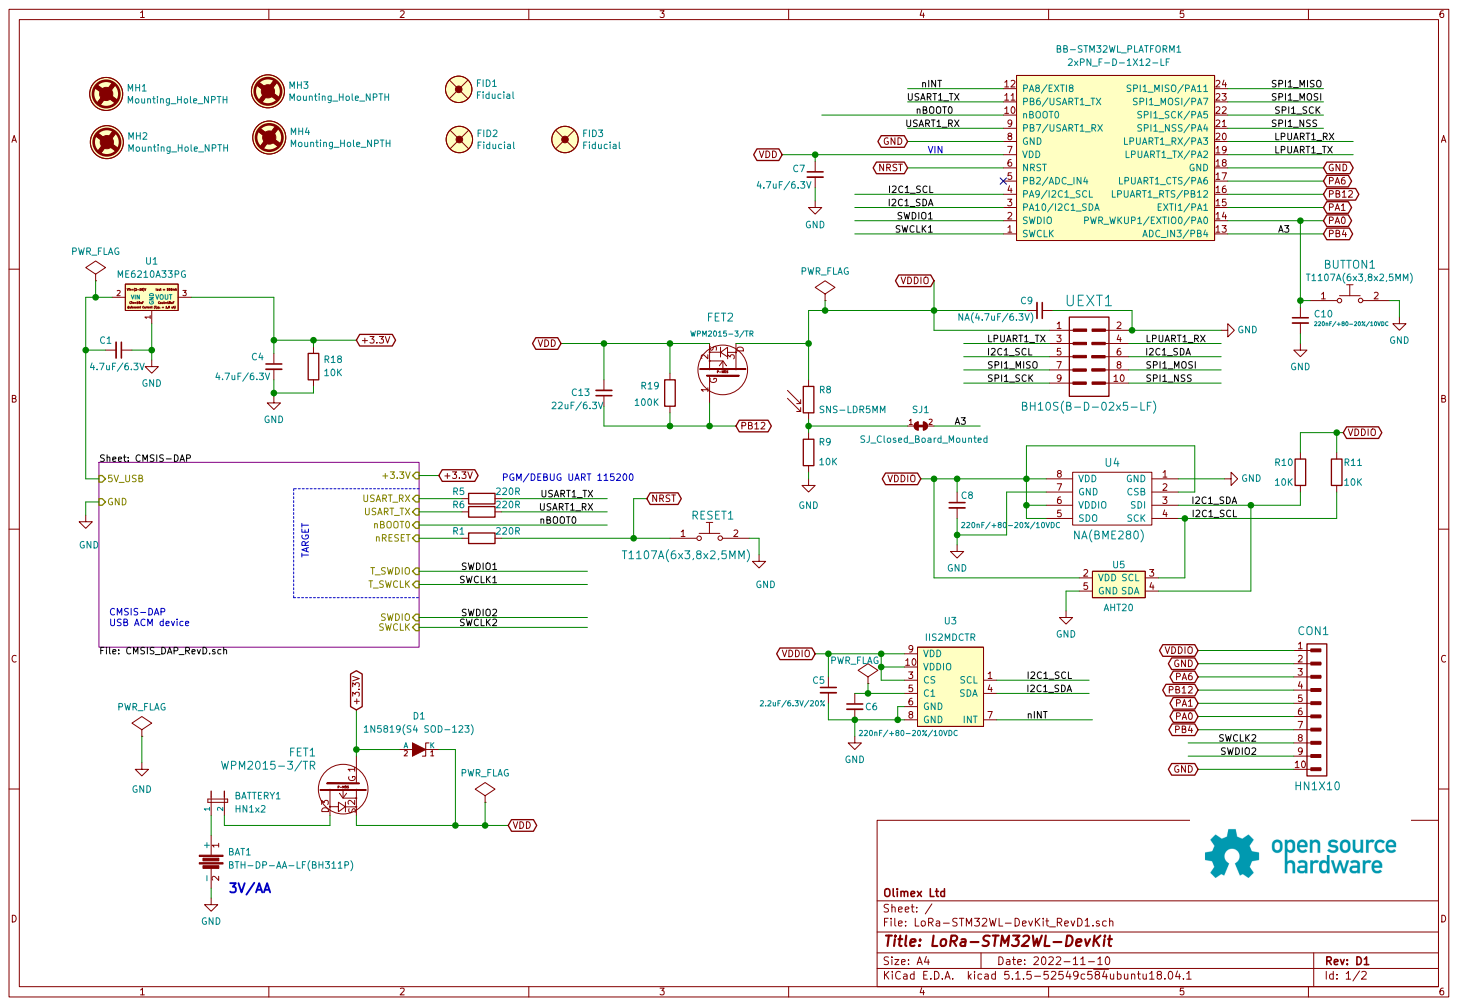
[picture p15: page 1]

3 FET2 WPM2015-3/TR GND GND GND

2 BATTERY1 HN1x2 GND GND 1 CSB 2 SDI 3 SCK 4 SDO 5 VDDIO 6 GND 7 VDD 8 U4 NA(BME280) D G

-2 BAT1 BTH-DP-AA-LF(BH311P) GND

File: LoRa-STM32WL-DevKit_RevD1.sch Sheet: / Olimex Ltd

Id: 1/2 Title: LoRa-STM32WL-DevKit

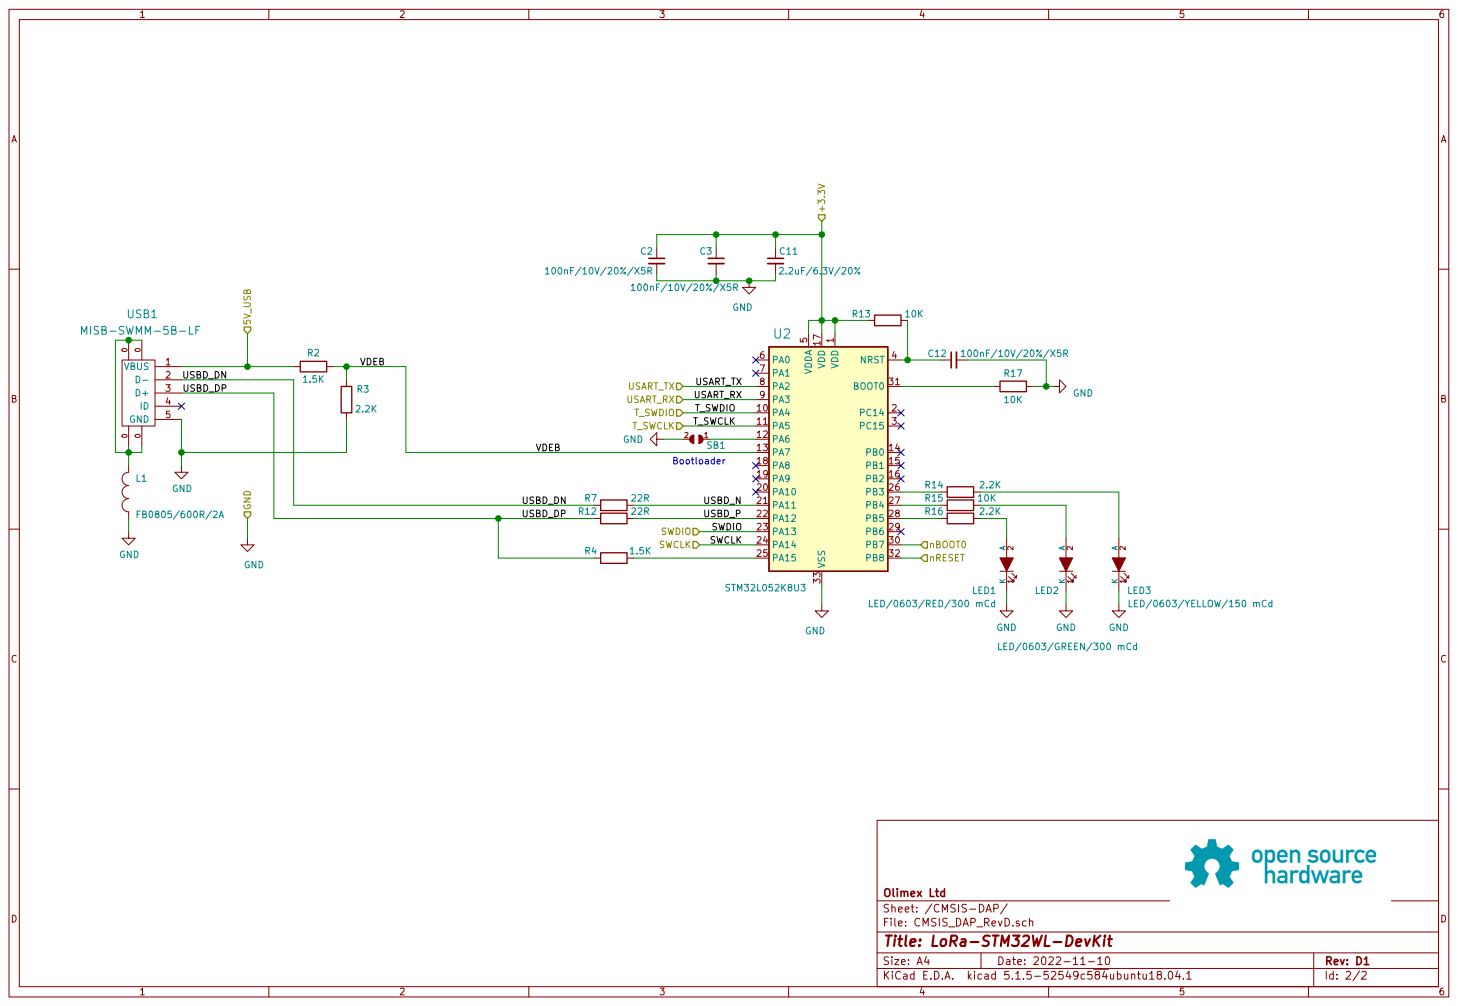
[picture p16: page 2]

1 PA4 10 PA5 11 PA6 12 PA7 13 PB0 14 PB1 15 PB2 16 VDD 17 PA8 18 PA9 19 PC14 2 PA10 20 PA11 21 PA12 22 PA13 23 PA14 24 PA15 25 PB3 26 PB4 27 PB5 28 PB6 29 PC15 3 PB7 30 BOOT0 31 PB8 32 VSS 33 NRST 4 VDDA

LED/0603/GREEN/300 mCd VDD

File: CMSIS_DAP_RevD.sch Sheet: /CMSIS-DAP/ Olimex Ltd

Id: 2/2 Title: LoRa-STM32WL-DevKit

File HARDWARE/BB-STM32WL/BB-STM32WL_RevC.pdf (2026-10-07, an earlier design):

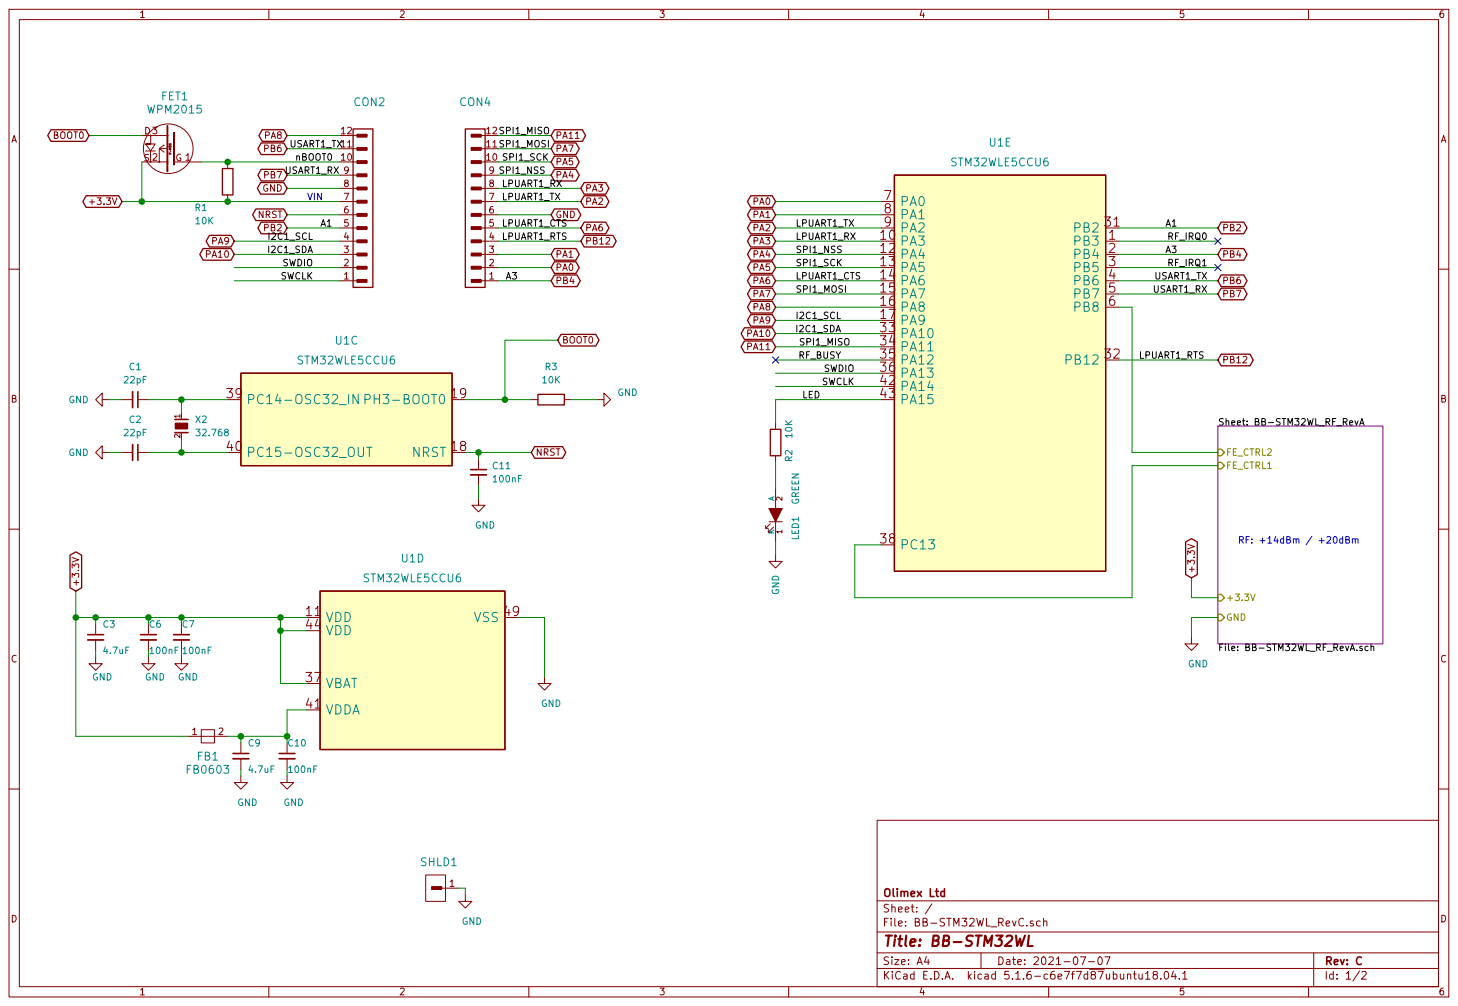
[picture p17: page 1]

File: BB-STM32WL_RF_RevA.sch +3.3V GND

File: BB-STM32WL_RevC.sch Sheet: / Olimex Ltd

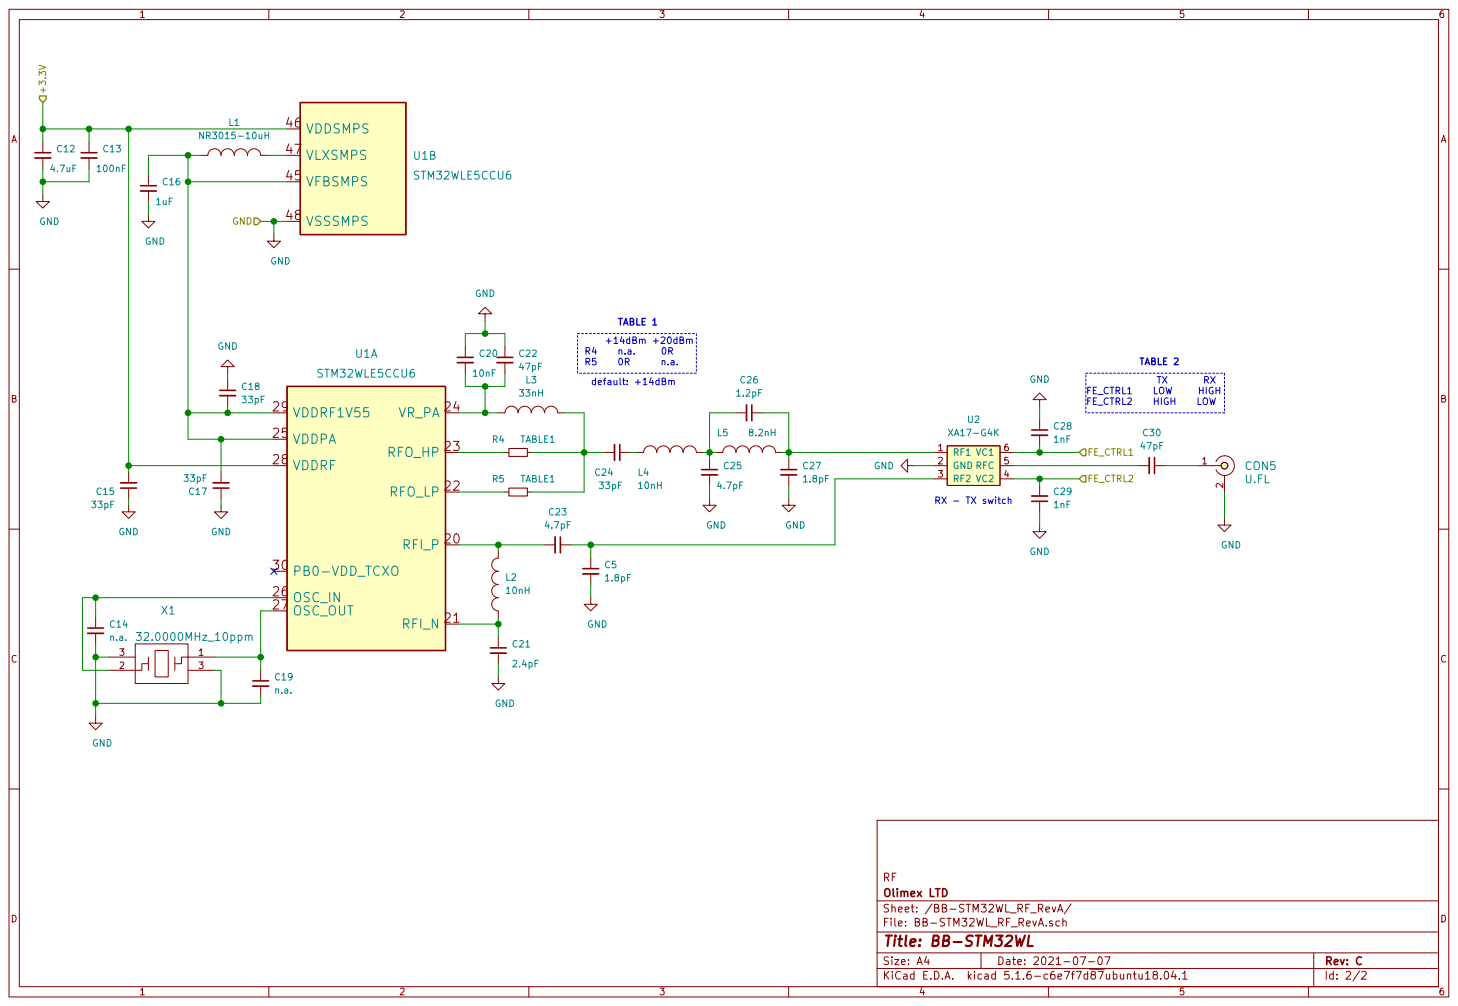
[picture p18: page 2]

Sheet: /BB-STM32WL_RF_RevA/ Olimex LTD

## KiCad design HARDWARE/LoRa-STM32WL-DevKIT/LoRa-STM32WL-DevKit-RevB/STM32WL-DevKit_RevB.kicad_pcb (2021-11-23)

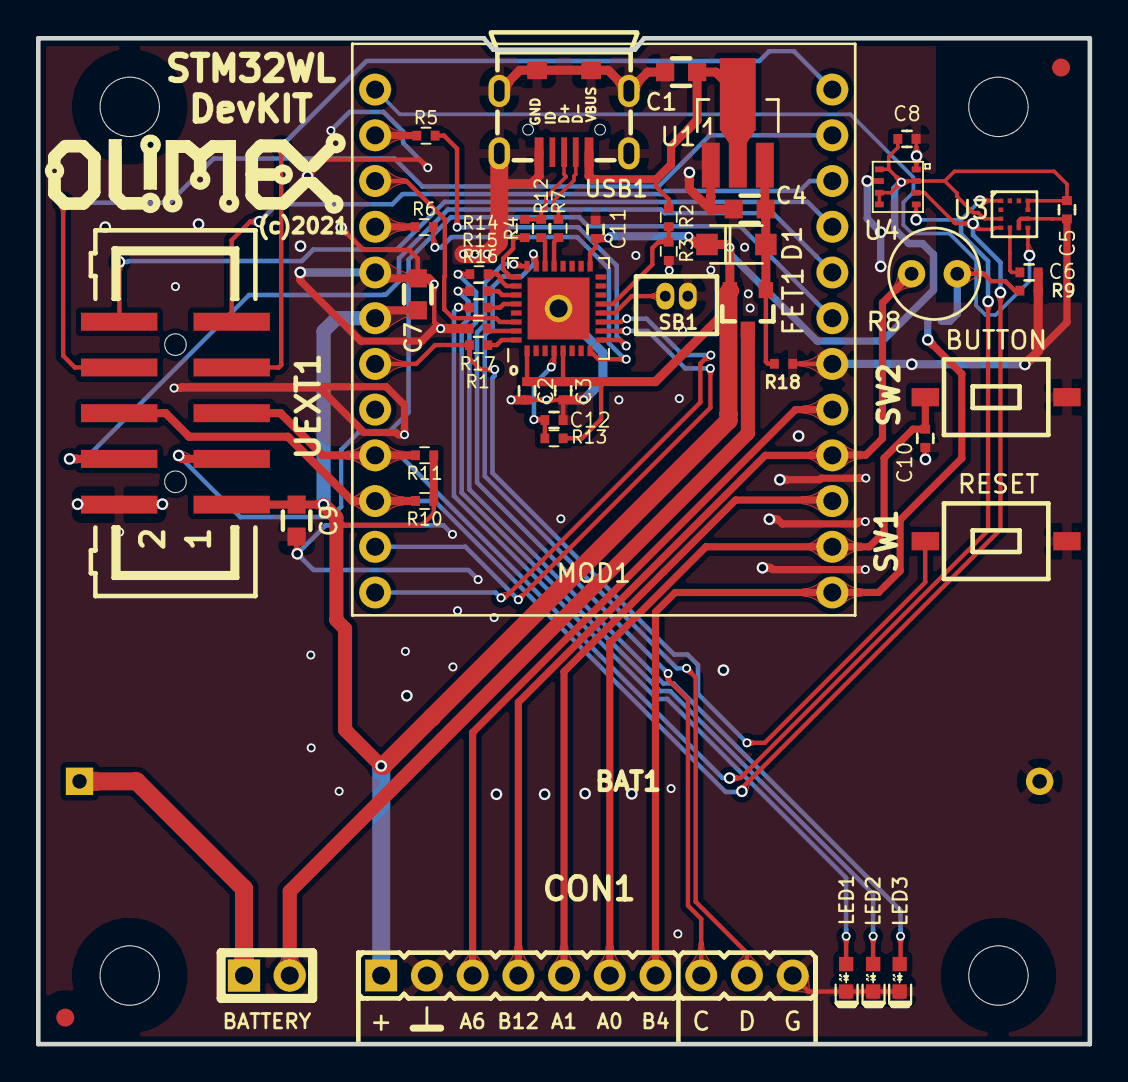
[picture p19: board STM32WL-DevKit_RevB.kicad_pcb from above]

Board: 4 copper layers, 58.4 x 55.9 mm, 55 parts (1 on the bottom side), 47 nets.

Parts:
BAT1: Battery; BATTERY-1xAA
C1, C4, C7, C9: 4.7uF_6.3V; C_0603_5MIL_DWS
C2, C3, C12: 100n; C_0402_5MIL_DWS
C5: 2.2uF_6.3V; C_0402_5MIL_DWS
C6, C8, C10: 220nF; C_0402_5MIL_DWS
C11: 2.2 uF; C_0402_5MIL_DWS
CON1: CON10; HN1x10
D1: 1N5819; SOD-123_KA
FET1: WPM2015; SOT23
JP2: JP1E; HN1x2_Jumper
LED1: RLED; LED_0603_KA
LED2: GLED; LED_0603_KA
LED3: YLED; LED_0603_KA
MOD1: BB-STM32WL; BB-STM32WLE
MountingHole*: Rubber_feet
MountingHole*#2, MountingHole*#3, MountingHole*#4: Rubber_feet
R1, R5, R6: 220R; R_0402_5MIL_DWS
R2, R4: 1.5K; R_0402_5MIL_DWS
R3, R14, R16: 2.2K; R_0402_5MIL_DWS
R7, R12: 22R; R_0402_5MIL_DWS
R8: R_PHOTO-Device; R_PHOTO
R9, R18: 10K; R_0402_SMALL
R10, R11: 10k; R_0402_5MIL_DWS
R13, R15, R17: 10K; R_0402_5MIL_DWS
Ref*: Val**; Fiducial1x3_transp
Ref*#2: Val**; Fiducial1x3_transp
SB1: SJ; WU02S
SJ1: SJ_Closed; SJ_1_SMALLER_TIED
SW1, SW2: T1107A(6x3,8x2,5MM)
U1: ME6210-SOT89; SOT89
U2: STM32L052K8Ux; QFN-32_EP_5.3x5.3_Pitch0.5mm
U3: IIS2MDC; LGA-12_2X2_0.5
U4: BME280
UEXT1: BH10S; GBH-254-SMT-10
USB1: USB-DEBUG; USB-MICRO_MISB-SWMM-5B_LF

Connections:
+3.3V: C4.1, D1.2, FET1.1, R18.2, U1.3
/CMSIS-DAP/5V_USB: C1.2, R2.2, U1.2, USB1.1
/CMSIS-DAP/USART_RX: R5.2, U2.9
/CMSIS-DAP/USART_TX: R6.2, U2.8
/CMSIS-DAP/USBD_DN: R7.1, USB1.2
/CMSIS-DAP/USBD_DP: R4.1, R12.1, USB1.3
/CMSIS-DAP/USBD_N: R7.2, U2.21
/CMSIS-DAP/USBD_P: R12.2, U2.22
/CMSIS-DAP/VDEB: R2.1, R3.2, U2.13
/CMSIS-DAP/nRESET: R1.2, U2.32
/SWCLK1: MOD1.1, U2.11
/SWCLK2: CON1.8, U2.24
/SWDIO1: MOD1.2, U2.10
/SWDIO2: CON1.9, U2.23
/nBOOT0: MOD1.10, U2.30
GND: BAT1.2, C1.1, C2.2, C3.2, C4.2, C5.2, C6.2, C7.2, C8.2, C9.1, C10.2, C11.2, C12.2, CON1.2, CON1.10, LED1.1, LED2.1, LED3.1, MOD1.8, MOD1.18, R3.1, R9.1, R17.1, R18.1, SB1.2, SW1.2, SW2.2, U1.1, U2.33, U3.6, U3.8, U4.1, U4.7, UEXT1.2, USB1.0, USB1.5
NRST: MOD1.6, R1.1, SW1.1
unnamed: BAT1.1, JP2.1
unnamed: C6.1, U3.5
unnamed: C12.1, R13.1, U2.4
unnamed: FET1.3, JP2.2
unnamed: LED1.2, R16.2
unnamed: LED2.2, R15.2
unnamed: LED3.2, R14.2
unnamed: R4.2, U2.25
unnamed: R14.1, U2.26
unnamed: R15.1, U2.27
unnamed: R16.1, U2.28
unnamed: R17.2, U2.31
unnamed: SB1.1, U2.12
PA0: C10.1, CON1.6, MOD1.14, SW2.1
PA1: CON1.5, MOD1.15
PA2: MOD1.19, UEXT1.3
PA3: MOD1.20, UEXT1.4
PA4: MOD1.21, UEXT1.10
PA5: MOD1.22, UEXT1.9
PA6: CON1.3, MOD1.17
PA7: MOD1.23, UEXT1.8
PA8: MOD1.12, U3.7
PA9: MOD1.4, R11.2, U3.1, U4.4, UEXT1.5
PA10: MOD1.3, R10.2, U3.4, U4.3, UEXT1.6
PA11: MOD1.24, UEXT1.7
PB4: CON1.7, MOD1.13, R8.2, R9.2, SJ1.1, SJ1.2
PB6: MOD1.11, R5.1
PB7: MOD1.9, R6.1
PB12: CON1.4, MOD1.16, R8.1
VDD: C2.1, C3.1, C5.1, C7.1, C8.1, C9.2, C11.1, CON1.1, D1.1, FET1.2, MOD1.7, R10.1, R11.1, R13.2, U2.1, U2.5, U2.17, U3.3, U3.9, U3.10, U4.2, U4.5, U4.6, U4.8, UEXT1.1

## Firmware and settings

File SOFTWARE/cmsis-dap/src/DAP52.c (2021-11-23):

/*
 * Copyright (c) 2015, Devan Lai
 *
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
 * THE SOFTWARE IS PROVIDED "AS IS" AND THE AUTHOR DISCLAIMS ALL
 * WARRANTIES WITH REGARD TO THIS SOFTWARE INCLUDING ALL IMPLIED
 * WARRANTIES OF MERCHANTABILITY AND FITNESS. IN NO EVENT SHALL THE
 * AUTHOR BE LIABLE FOR ANY SPECIAL, DIRECT, INDIRECT, OR
 * CONSEQUENTIAL DAMAGES OR ANY DAMAGES WHATSOEVER RESULTING FROM
 * LOSS OF USE, DATA OR PROFITS, WHETHER IN AN ACTION OF CONTRACT,
 * NEGLIGENCE OR OTHER TORTIOUS ACTION, ARISING OUT OF OR IN
 * CONNECTION WITH THE USE OR PERFORMANCE OF THIS SOFTWARE.
 */

#include <stdio.h>
#include <string.h>

#include <libopencm3/stm32/desig.h>
#include <libopencm3/stm32/iwdg.h>

#include <libopencm3/stm32/rcc.h>
#include <libopencm3/stm32/crs.h>
#include <libopencm3/stm32/gpio.h>
#include <libopencm3/stm32/syscfg.h>

#include "config.h"
#include "target.h"

#include "USB/composite_usb_conf.h"
#include "USB/cdc.h"
#include "USB/vcdc.h"
#include "USB/dfu.h"

#include "DAP/app.h"
#include "DAP/CMSIS_DAP_hal.h"
#include "DFU/DFU.h"


#include "tick.h"
#include "retarget.h"
#include "console.h"


extern void initialise_monitor_handles(void);

static inline uint32_t millis(void) {
    return get_ticks();
}

static inline void wait_ms(uint32_t duration_ms) {
    uint32_t now = millis();
    uint32_t end = now + duration_ms;
    if (end < now) {
        end = 0xFFFFFFFFU - end;
        while (millis() >= now) {
            __asm__("NOP");
        }
    }

    while (millis() < end) {
        __asm__("NOP");
    }
}

static uint32_t usb_timer = 0;
static void on_usb_activity(void) {
    usb_timer = 1000;
}

static bool do_reset_to_dfu = false;
static void on_dfu_request(void) {
    do_reset_to_dfu = true;
}


int main(void) {
    if (DFU_AVAILABLE) {
        DFU_maybe_jump_to_bootloader();
    }

    cpu_setup();
    clock_setup();
    tick_setup(1000);
    gpio_setup();
    led_num(0);


    if (CDC_AVAILABLE) {
        console_setup(DEFAULT_BAUDRATE);
	retarget(STDOUT_FILENO, CONSOLE_USART);
        retarget(STDERR_FILENO, CONSOLE_USART);
    }
/*
    if (SEMIHOSTING) {
        initialise_monitor_handles();
    }
    else if (VCDC_AVAILABLE) {
        retarget(STDOUT_FILENO, VIRTUAL_USART);
        retarget(STDERR_FILENO, VIRTUAL_USART);
    } else 
    if (CDC_AVAILABLE) {
        retarget(STDOUT_FILENO, CONSOLE_USART);
        retarget(STDERR_FILENO, CONSOLE_USART);
    }
*/  
 
 
    {
        char serial[USB_SERIAL_NUM_LENGTH+1];
        desig_get_unique_id_as_string(serial, USB_SERIAL_NUM_LENGTH+1);
        cmp_set_usb_serial_number(serial);
    }
       
 
    usbd_device* usbd_dev = cmp_usb_setup();
    DAP_app_setup(usbd_dev, &on_dfu_request);
    

    
    if (CDC_AVAILABLE) {
        cdc_uart_app_setup(usbd_dev, &on_usb_activity, &on_usb_activity);
        cdc_uart_app_set_timeout(1);
    }
    if (DFU_AVAILABLE) {
        dfu_setup(usbd_dev, &on_dfu_request);
    }

    if (VCDC_AVAILABLE) {
        vcdc_app_setup(usbd_dev, &on_usb_activity, &on_usb_activity);
    }


   

    /* Enable the watchdog to enable DFU recovery from bad firmware images */
    iwdg_set_period_ms(1000);
    iwdg_start();
    led_num(4);
    tick_start();


    while (1) {
	

	
        iwdg_reset();
        usbd_poll(usbd_dev);

        if (CDC_AVAILABLE) {
            cdc_uart_app_update();
        }


        // Handle DAP
        bool dap_active = DAP_app_update();
        if (dap_active) {
            usb_timer = 1000;
        } 

	else if (do_reset_to_dfu && DFU_AVAILABLE) {
            // Blink 3 times to indicate reset 
            int x;
            for (x=0; x < 3; x++) {
                iwdg_reset();
                led_num(7);
                wait_ms(150);
                led_num(0);
                wait_ms(150);
                iwdg_reset();
            }

            DFU_reset_and_jump_to_bootloader();
        }

        if (usb_timer > 0) {
            usb_timer--;
            LED_ACTIVITY_OUT(1);
        } else {
            LED_ACTIVITY_OUT(0);
        }
    }

    return 0;
}

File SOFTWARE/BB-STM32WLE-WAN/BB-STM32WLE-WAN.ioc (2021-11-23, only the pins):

Mcu.UserName=STM32WLE5CCUx
PA0.Signal=GPXTI0
PA1.Signal=GPXTI1
PA10.Signal=I2C1_SDA
PA11.Signal=SPI1_MISO
PA13.Signal=DEBUG_JTMS-SWDIO
PA15.GPIO_Label=LED
PA15.Signal=GPIO_Output
PA2.Signal=LPUART1_TX
PA3.Signal=LPUART1_RX
PA4.Signal=SPI1_NSS
PA5.Signal=SPI1_SCK
PA6.Signal=GPXTI6
PA7.Signal=SPI1_MOSI
PA8.Signal=GPIO_Analog
PA9.Signal=I2C1_SCL
PB0-VDD_TCXO.Signal=GPIO_Analog
PB12.GPIO_Label=AMB_PWR
PB12.Signal=GPIO_Output
PB2.GPIO_Label=DUMMY
PB2.Signal=GPIO_Output
PB3.GPIO_Label=LED2
PB3.Signal=GPIO_Output
PB4.GPIO_Label=AMB
PB4.Signal=SharedAnalog_PB4
PB5.GPIO_Label=LED3
PB5.Signal=GPIO_Output
PB6.Signal=USART1_TX
PB7.Signal=USART1_RX
PB8.GPIO_Label=FE_CTRL2
PB8.Signal=GPIO_Output
PC13.GPIO_Label=FE_CTRL1
PC13.Signal=GPIO_Output
PC14-OSC32_IN.Signal=RCC_OSC32_IN
PC15-OSC32_OUT.Signal=RCC_OSC32_OUT

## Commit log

2021-11-23 initial upload docs
    [18650.step, 434121043836 (rev1).stp, BAT_1xAA_HOLDER.step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]
2022-02-02 Fix
    Added missing files
    [iis2mdc_reg.c, iis2mdc_reg.h]
2023-03-29 Update
    Hardware revision D1
    [434121043836 (rev1).stp, BAT_1xAA_HOLDER.step, BCAAPC.STEP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]
2023-12-20 Update
    Demo updated for latest hardware revision with power control pin and new AHT20 sensor
2026-10-07 Update
    New hardware revision D1
    [18650.step, 434121043836 (rev1).stp, BAT_1xAA_HOLDER.step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]

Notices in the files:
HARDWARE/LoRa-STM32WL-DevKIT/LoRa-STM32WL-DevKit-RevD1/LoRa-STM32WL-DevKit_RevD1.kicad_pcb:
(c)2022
